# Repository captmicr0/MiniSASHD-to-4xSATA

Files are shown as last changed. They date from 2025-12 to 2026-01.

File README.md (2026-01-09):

# MiniSASHD-to-4xSATA

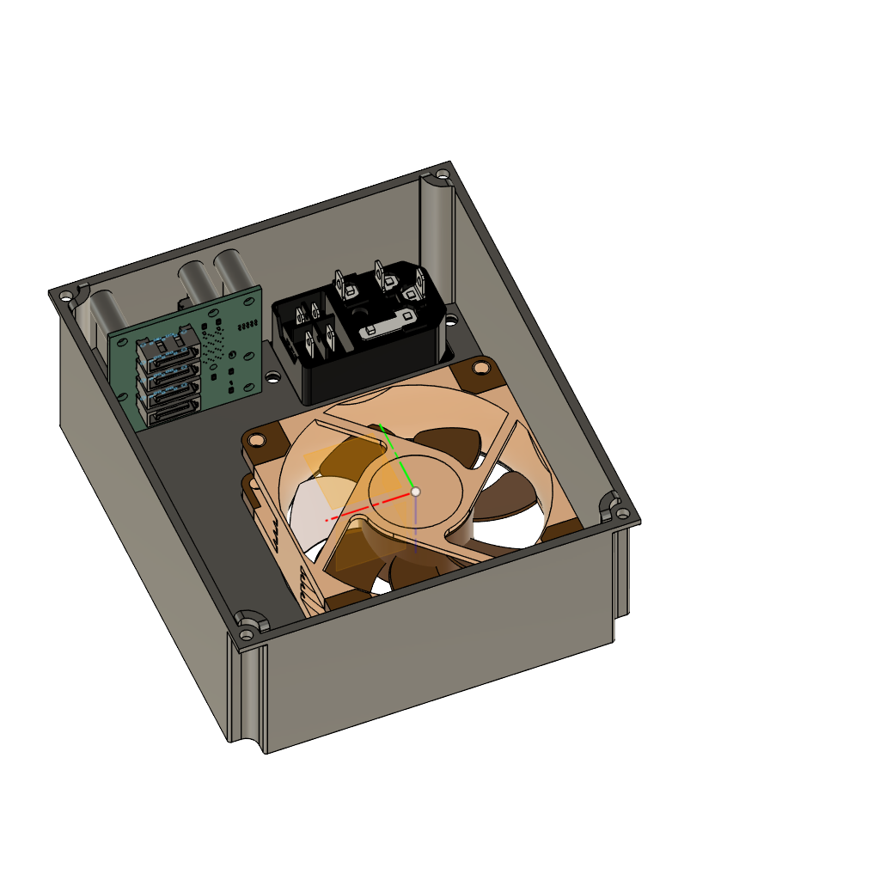
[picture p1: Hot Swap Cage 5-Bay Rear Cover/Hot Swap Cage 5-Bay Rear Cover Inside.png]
Inside Front


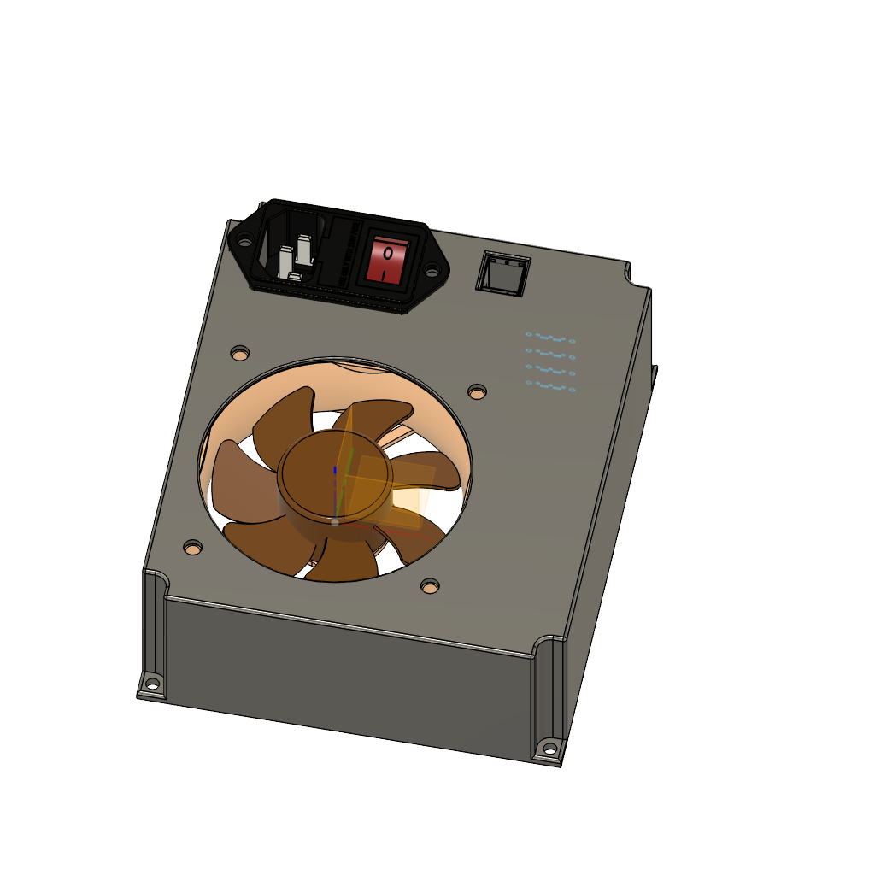
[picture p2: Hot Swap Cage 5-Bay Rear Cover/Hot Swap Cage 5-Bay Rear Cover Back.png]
Back


---
**Parts for PSU:**
- 12V 150W LED Driver / PSU (MUST BE 14.1cm * 5cm * 2.3cm OR SMALLER)

  Part Used: [12V 150W LED Driver Ultra Slim](https://www.amazon.com/dp/B0CWNQQKGL)

- IEC320 C14 Power Inlet Module with Fuse and Rocker Switch

  Part Used: [2‑Pack IEC320 C14 Power Inlet Module with Fuse and Rocker Switch](https://www.amazon.com/dp/B0FZKT33MP)

- 12V to 5V 5A 25W Step Down Converter

  Part Used: [DC 24V 12V to 5V 5A 25W Step Down Converter Module](https://www.amazon.com/dp/B0CRVWDVHG)

  Use a WAGO connector or just solder the 5V output to the 5V pin on the Molex connector

- Molex Splitter to salvage Connector + Wire (cheapest option)

  Part Used: [StarTech.com LP4 to 2X LP4 Power Y Splitter Cable M/F  (PYO2L)](https://www.amazon.com/dp/B000067SLY)

---
**Parts for PCB:**

- I/O Connector, 36 Contacts, Receptacle, Mini SAS HD, Press Fit, PCB Mount

  Part Used: [EDAC 904-036-225-002](https://www.newark.com/edac/904-036-225-002/mini-sas-hd-conn-rcpt-36pos-press/dp/78AC5807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)

  M2 screw needed to attach to PCB, approx 4-6mm long depending on connector mfg. 

- 7 Position SATA Header, Shrouded Connector Solder Through Hole

  Part Used: [Molex 067800-8025](https://www.digikey.com/en/products/detail/molex/0678008025/3044663)

---
**Cables for Attaching to Host:**

- 6" SATA Data Cable

  Part Used: [Dell 0GVJ31](https://www.ebay.com/itm/325255575187)

- 0.5m Mini-SAS HD cable (SFF-8644 to SFF-8644)

  Part Used: [10Gtek 12G Mini SAS HD SFF-8644 to SFF-8644 Cable](https://www.amazon.com/gp/product/B0836TTZJ4)

---
**My Specific Host Setup:**

- 0.3m Mini-SAS HD cable (SFF-8643 to SFF-8643)

  Part Used: [IBM 00FK817](https://www.ebay.com/itm/405669346130) 

  Alternate: [H!Fiber.com 12G Internal Mini SAS HD SFF-8643 to SFF-8643 Cable](https://www.amazon.com/gp/product/B0BX96QK3B)

  Used to attach the below adapter to LSI 9305-16i HBA.

- Internal SFF-8643 to External SFF-8644 Low-Profile Adapter

  Part Used: [Supermicro AOM-SAS3-8I8E-LP](https://www.ebay.com/itm/283861780557)

  This is the cheapest interal-to-external mini-sas hd adapter you can find.

---
***Ensure total cable length from your HBA's port to the HDD's port is no longer than 1m TOTAL***

In my case the math adds up as shown:

<pre>
HBA -> Adapter:    0.30m (11.8")
Adapter (approx):  0.05m (   2")
Adapter -> PCB:    0.50m (19.7")
PCB -> Backplane:  0.15m (   6")
Backplane -> HDD:  0.08m (   3")
Total:             1.08m
</pre>

Just over the 1m SATA cable length limit... Should be fine!

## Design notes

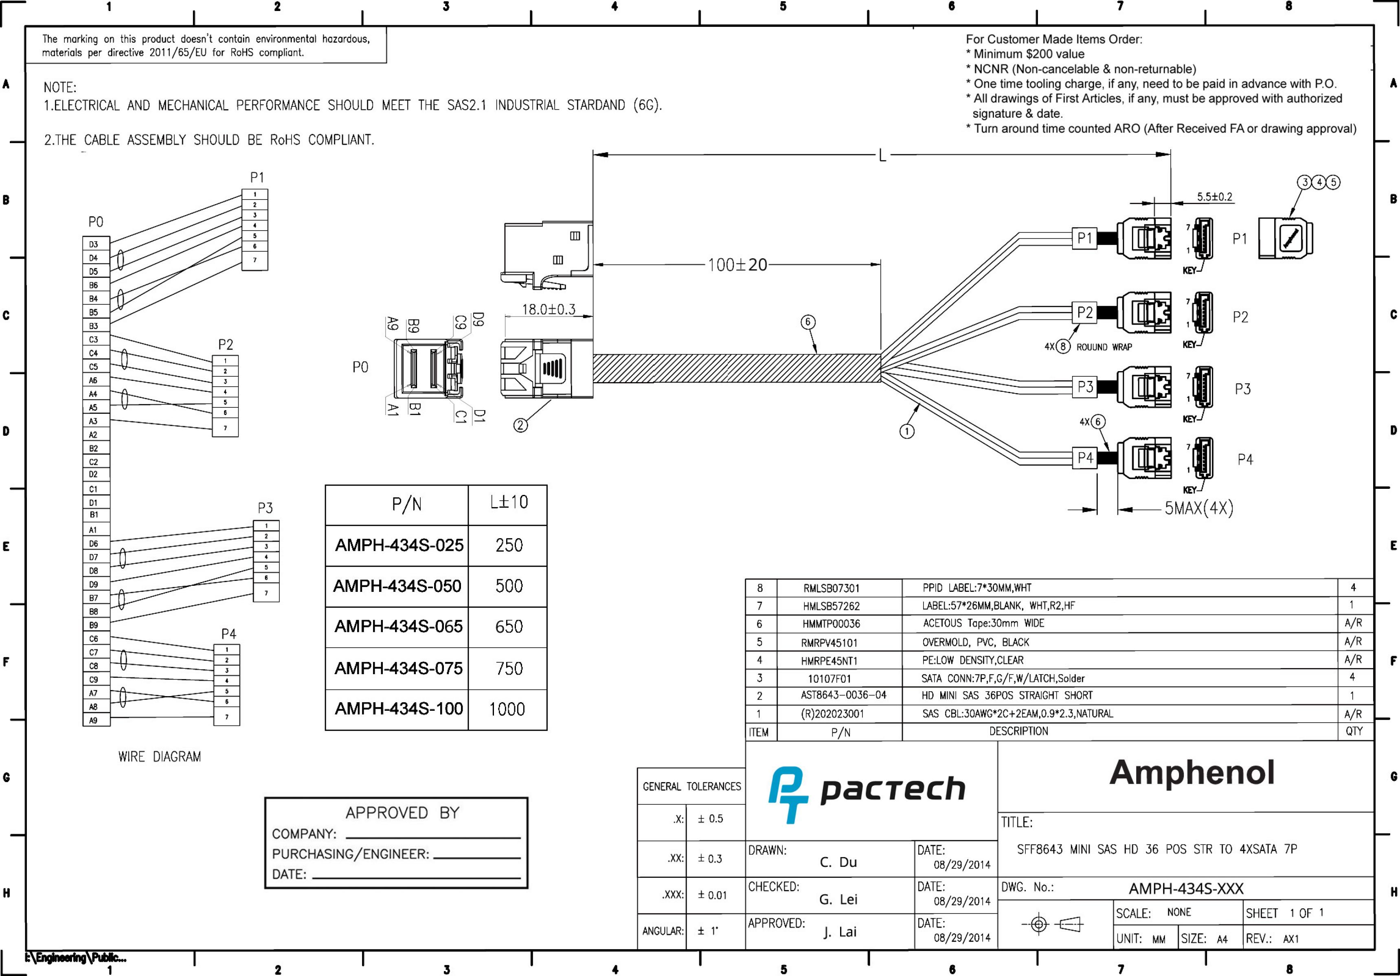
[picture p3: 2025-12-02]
AMPH-434S-065-sent-out-_01.jpg

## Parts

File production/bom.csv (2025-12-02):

Designator | Footprint | Quantity | Value | LCSC Part #
FB1, FB2, FB3, FB4, FB5, FB6, FB7 | 0805 | 7 | FerriteBead_Small
J1 | COMBO SFF-8644 SFF-8643 | 1 | 2149027-1
J2, J3, J4, J5 | CONN_67800-8025_MOL | 4 | 678008025
J6 | PinHeader_2x05_P1.27mm_Vertical | 1 | Conn_01x10

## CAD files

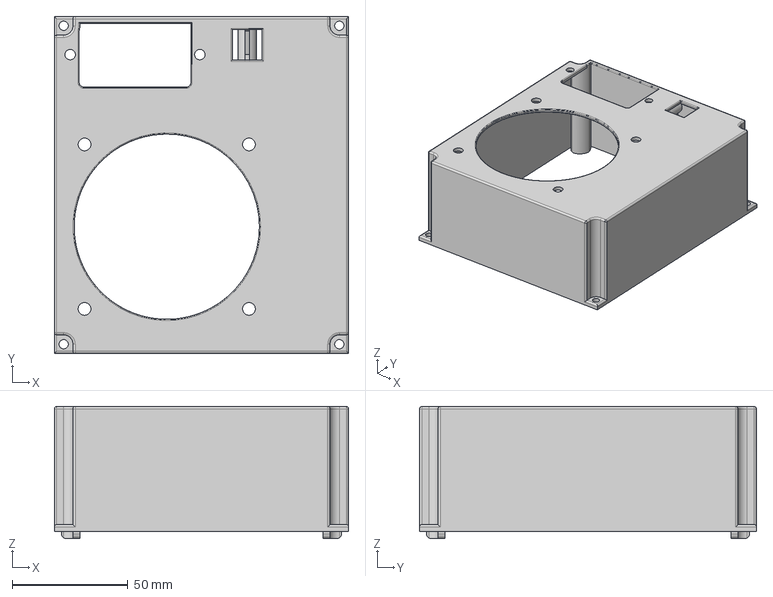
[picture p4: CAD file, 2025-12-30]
Hot Swap Cage 5-Bay Rear Cover/Hot Swap Cage 5-Bay Rear Cover.step
127.0 x 145.5 x 57.0 mm

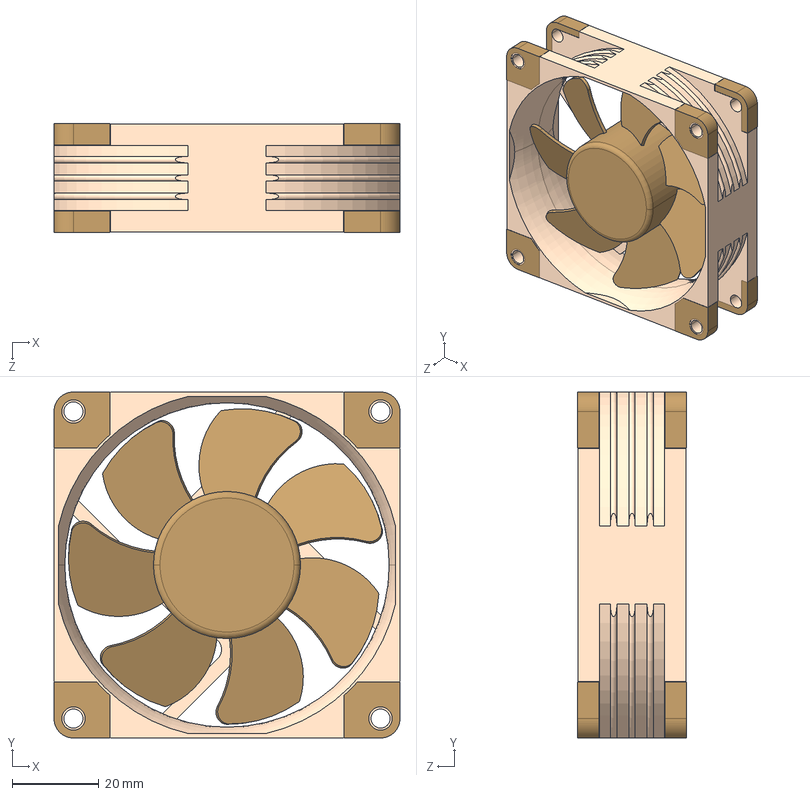
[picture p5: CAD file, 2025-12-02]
Hot Swap Cage 5-Bay Rear Cover/Noctua nf-a8-pwm fan 80x80x25.STEP
80.0 x 80.0 x 25.2 mm

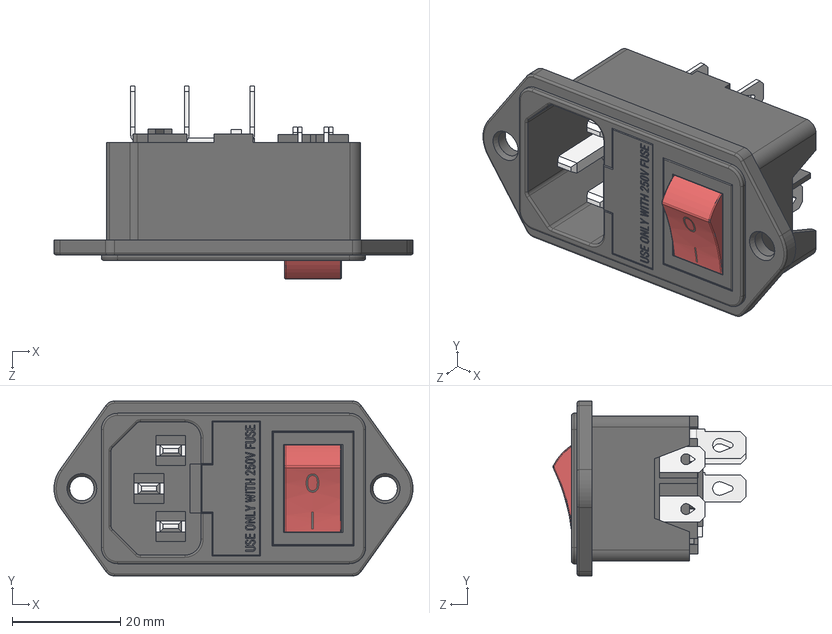
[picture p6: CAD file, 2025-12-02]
Hot Swap Cage 5-Bay Rear Cover/AC_Power_Socket-3_pin_250V_10A_AC-17.STEP
66.3 x 32.3 x 35.6 mm
Case_PC
Êîíòàêò x 2
扻艜魛瀖GND
抔樥憵 x 3
扻艜魛瀖fuse x 2
Fuse_holder x 2
Ïåðåìû÷êà
SWITCH KCD1-104_Default<As Machined>
Äåðæàòåëü_ïðåäîõðàíèòåëÿ
Fuse Small 1A

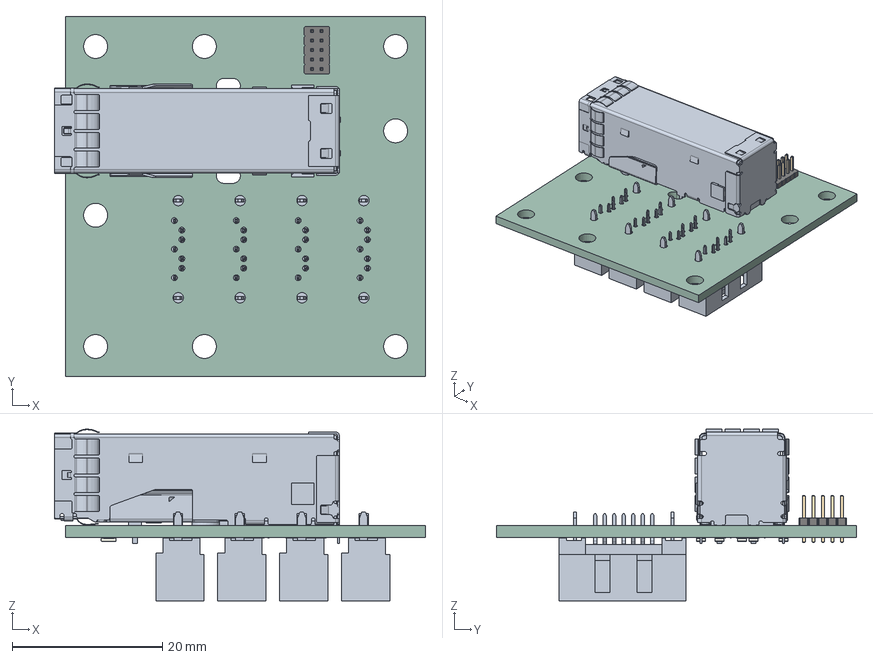
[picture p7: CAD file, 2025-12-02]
Hot Swap Cage 5-Bay Rear Cover/MiniSASHD to 4xSATA.step
49.5 x 48.0 x 22.9 mm
PinHeader_2x05_P127mm_Vertical
C-2149027-1
R_0805_2012Metric x 7
MiniSASHD to 4xSATA_PCB

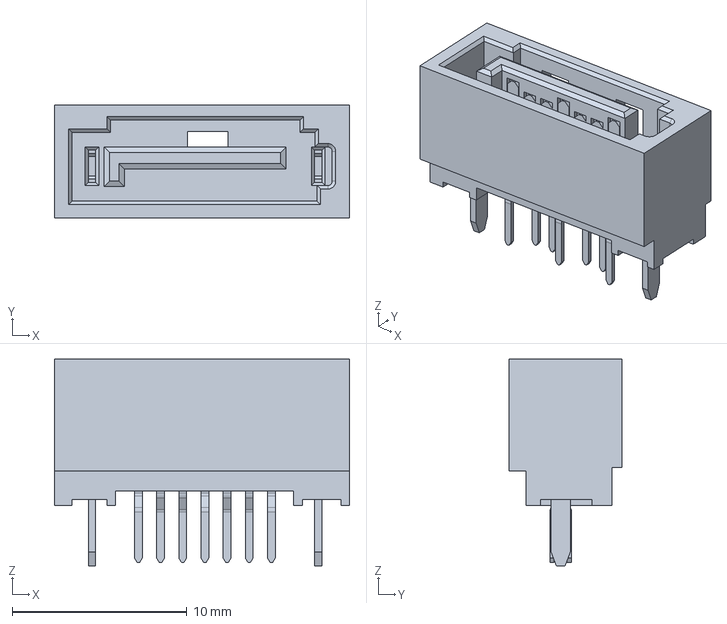
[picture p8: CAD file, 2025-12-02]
kicad_parts_used/67800-8025/678008025.stp
16.9 x 6.45 x 11.9 mm

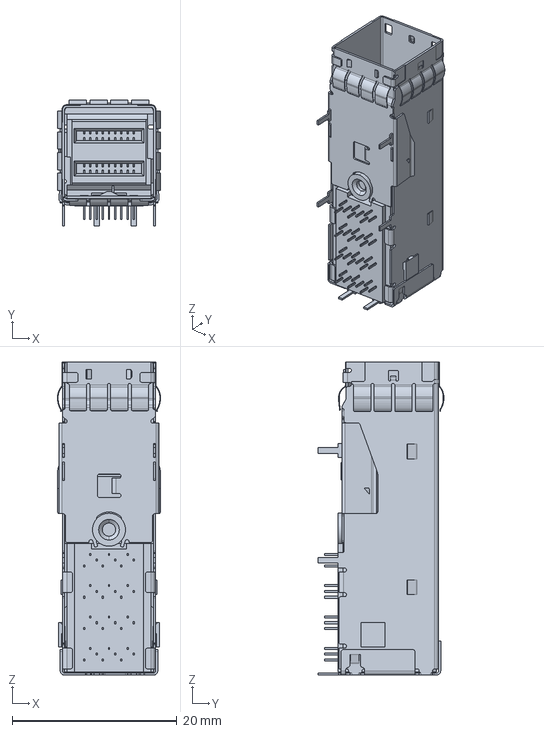
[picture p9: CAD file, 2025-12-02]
kicad_parts_used/TE 2149027-1/2149027-1.step
12.5 x 15.3 x 38.0 mm

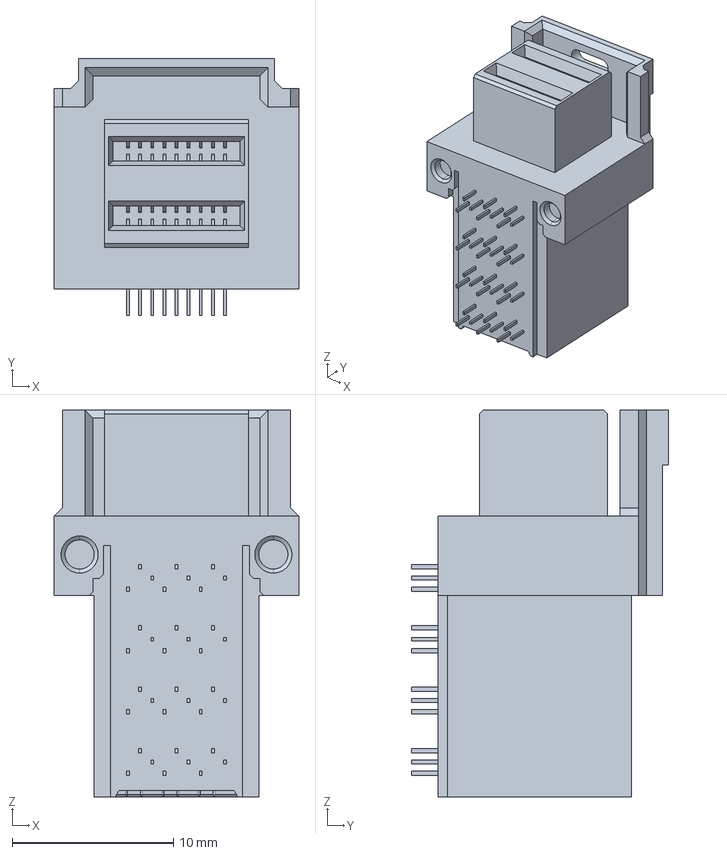
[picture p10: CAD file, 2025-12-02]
kicad_parts_used/TE 2227580-1/2227580-1.STEP
15.2 x 15.9 x 24.0 mm

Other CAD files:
Hot Swap Cage 5-Bay Rear Cover/Hot Swap Cage 5-Bay Rear Cover.3mf

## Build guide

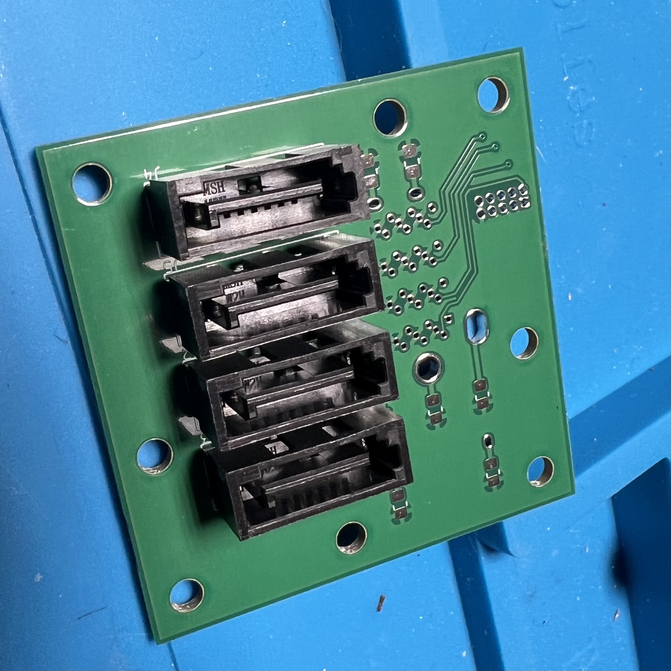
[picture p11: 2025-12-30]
Hot Swap Cage 5-Bay Rear Cover/build/pcb without minisas hd connector.jpeg

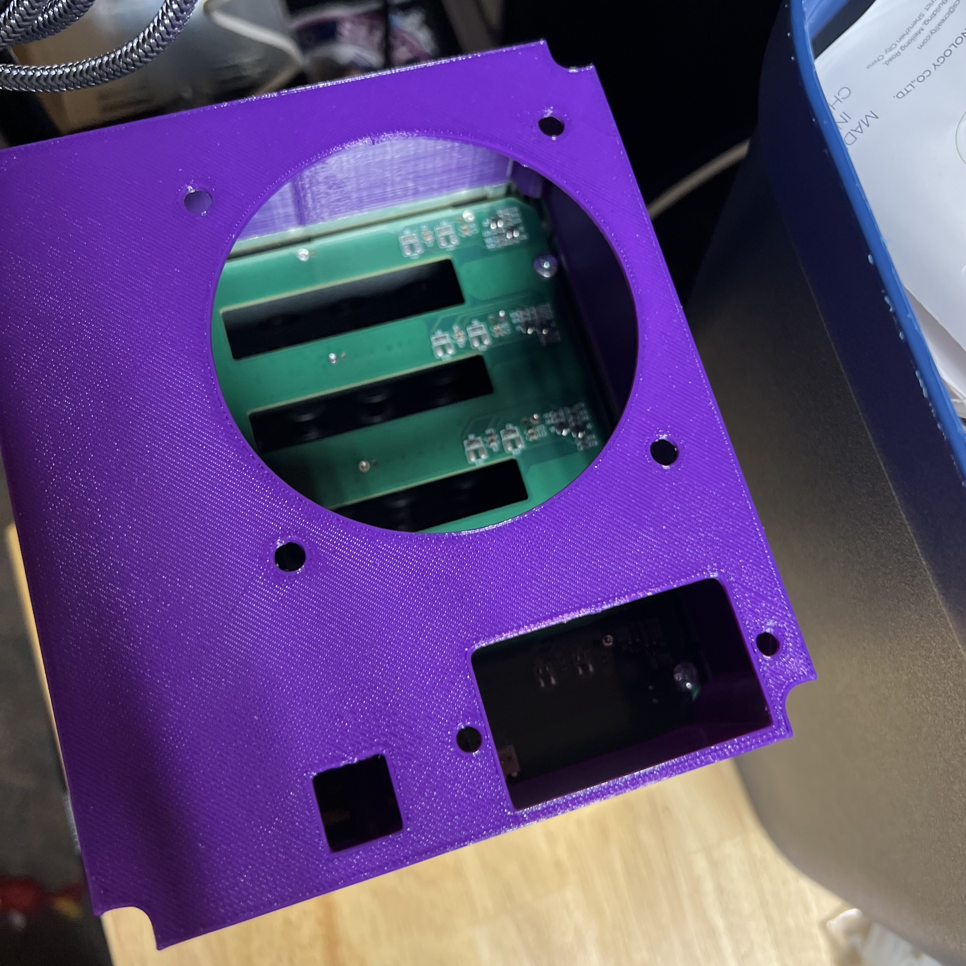
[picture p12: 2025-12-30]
Hot Swap Cage 5-Bay Rear Cover/build/cage with new rear cover.jpeg

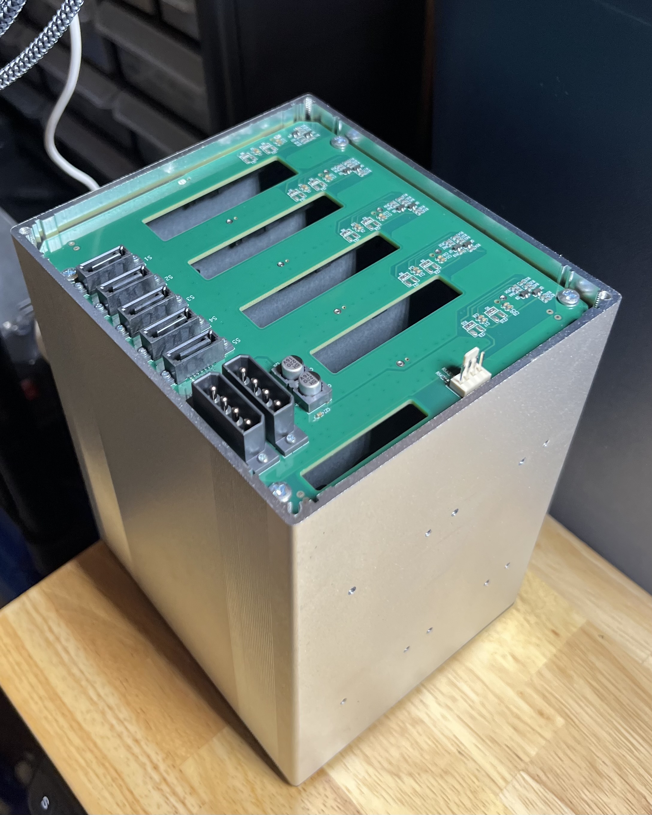
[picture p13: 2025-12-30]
Hot Swap Cage 5-Bay Rear Cover/build/cage without rear cover.jpeg

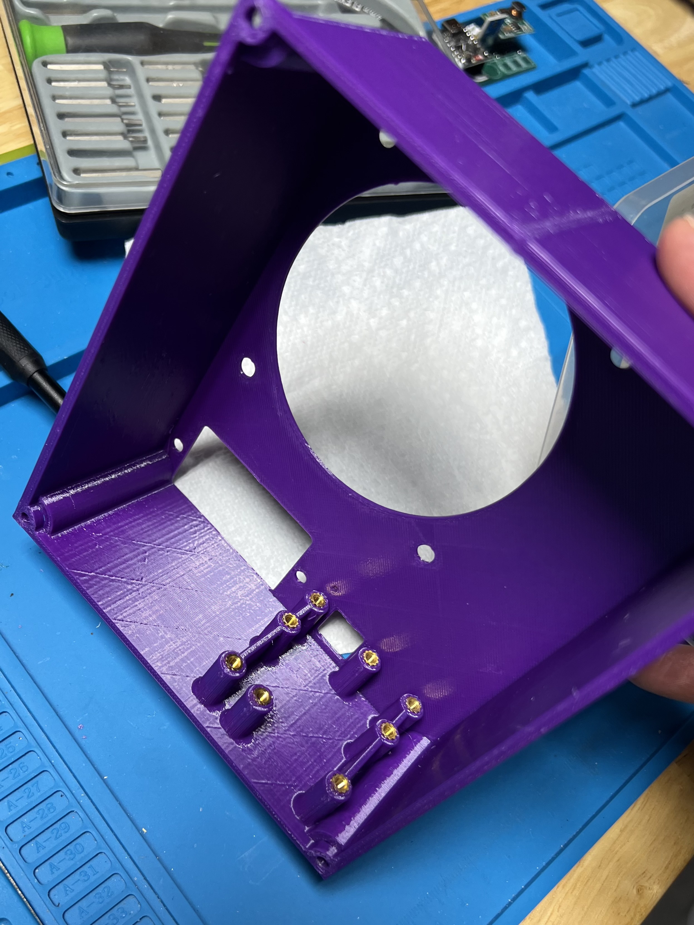
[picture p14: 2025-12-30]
Hot Swap Cage 5-Bay Rear Cover/build/heat set inserts.jpeg

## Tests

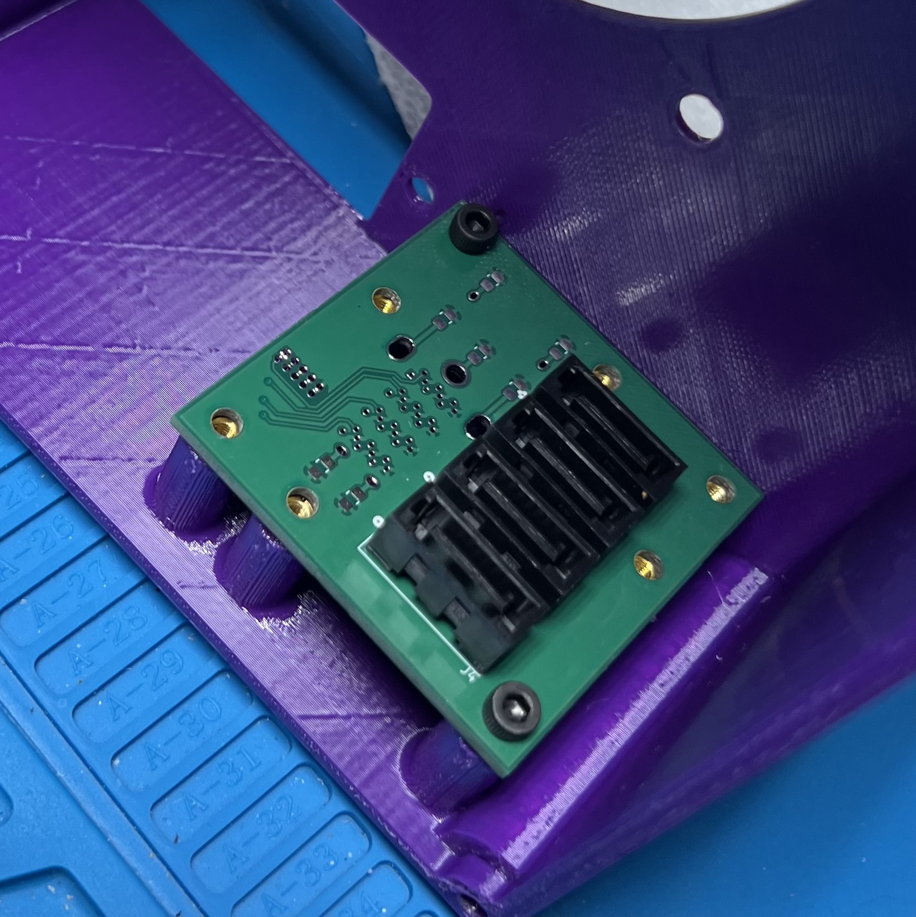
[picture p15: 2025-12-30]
Hot Swap Cage 5-Bay Rear Cover/build/pcb test fit 1.jpeg

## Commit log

2025-12-02 modified dir structure
    [2149027-1.step, 2227580-1.STEP, 678008025.stp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]
2025-12-30 fixed heat set insert holes, softened edges, enlarged MiniSAS HD hole
    [Hot Swap Cage 5-Bay Rear Cover - Ender3_V3_SE_PETG_235C_75C.3mf, Hot Swap Cage 5-Bay Rear Cover.3mf, Hot Swap Cage 5-Bay Rear Cover.step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]
